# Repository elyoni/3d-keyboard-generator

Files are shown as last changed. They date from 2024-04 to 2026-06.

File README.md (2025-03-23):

# 3D Keyboard Builder

## Motivation (Short Version)

After experimenting with various custom keyboards, including the Ergodox and my own hand-built designs, I realized I wanted something more flexible and hot-swappable. My journey led me to a project that inspired me to create my own fully customizable keyboard, allowing me to test different layouts and components. This project not only solves my ergonomic needs but also provides the creative freedom to explore new features. <F12>

[Go here to read the full motivation story](<#motivation-(full-version)>)

## Project Description

This application takes a JSON file output from KLE and generates three STL files that are ready for 3D printing:

1. **Plate**: The top layer that holds the switches.
2. **PCB**: The layer designed to house the electronic components.
3. **Bottom**: The bottom layer, which encloses the keyboard.

The script processes each element of the KLE JSON to create a precise, functional 3D model for your custom keyboard.

## Supported Parts

### Keys

- **Cherry MX switches**

```json
[{sm:"cherry",a:7},"Q","W","E","R"],
["A",{w:2},"S","F"],
["Z","X","C"],
[{r:30,y:-3,x:4.25},"V"]
```

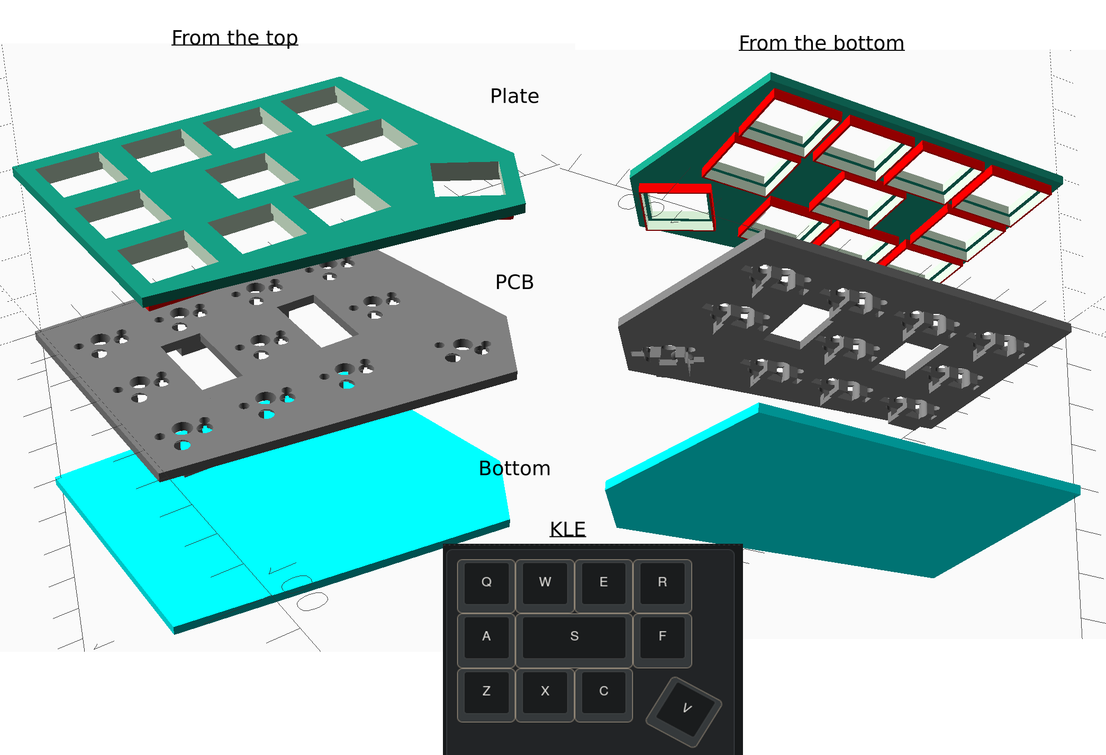
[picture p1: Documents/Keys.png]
Keys


### Arduino

- **Arduino** with Type C connection support

```json
[{ "y": 0.2, "x": 5.9, "sm": "arduino", "a": 5, "h": 2 }, "Arduino"]
```

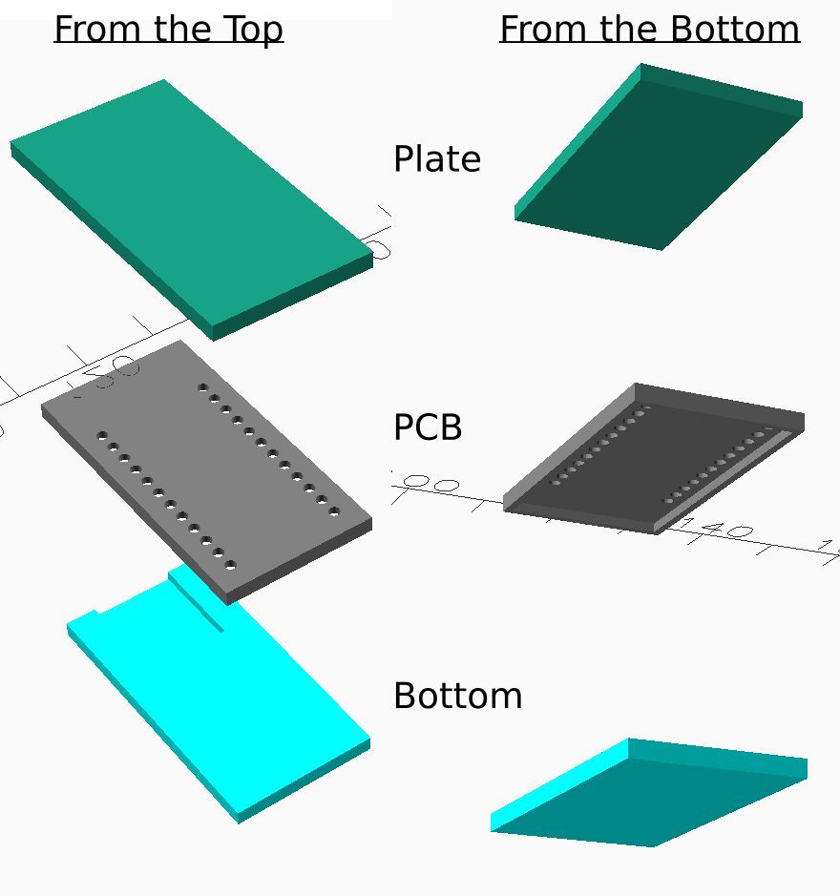
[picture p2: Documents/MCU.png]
Mcu


Links:

- [AliExpress: Arduino micro pro - ATMEGA32U4; $3.38](https://www.aliexpress.com/item/32840365436.html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)
- [AliExpress: Kailh Hot-swappable Cherry MX Switches 70pcs;$4.23](https://www.aliexpress.com/item/1005007052649640.html?spm=a2g0o.order_list.order_list_main.208.587a586aZr4UDJ)

### Pins (Layer Connectors)

- Pins act as placeholders for screws, providing modular assembly of keyboard layers.
- **Pin Types**:
  - **PinPcb**: Connects the Bottom layer to the PCB.
  - **PinPlate**: Connects the PCB to the Plate.
  - **PinB2P**: Direct connection between the Bottom layer and the Plate.

```json
[{sm:"pinpcb",w:0.5,h:0.5},"PinPcb"],
[{y:-0.25,sm:"pinplate",w:0.5,h:0.5},"PinPlate"],
[{y:-0.25,sm:"pinb2t",w:0.5,h:0.5},"PinB2P"]
```

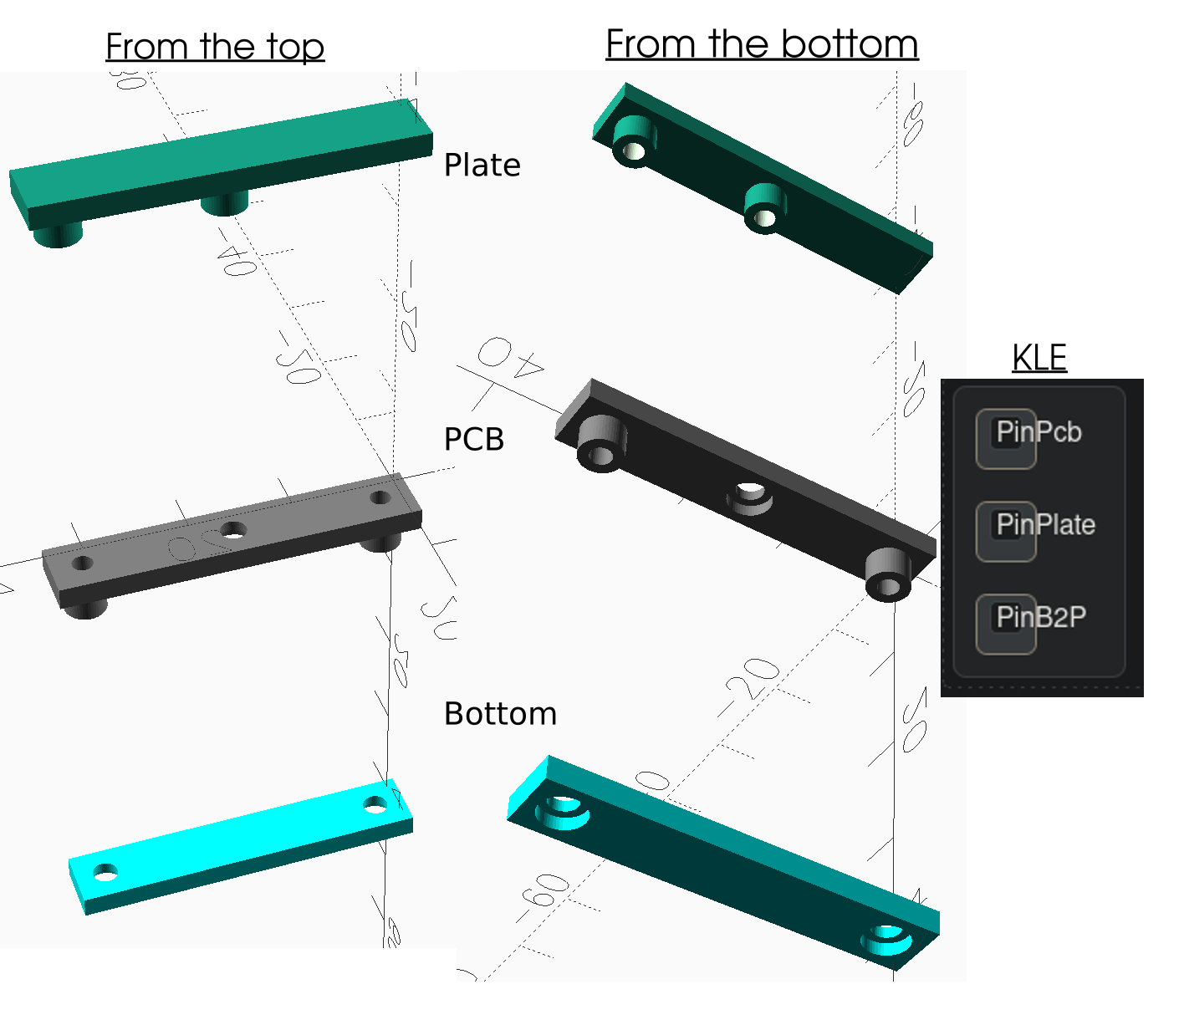
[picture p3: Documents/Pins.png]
Pin


### Split Keyboard Connector

- **TRRS Connector**: Support for split keyboard designs with TRRS connections.

Links:

- (AliExpress: TRRS 3.5 MM Audio Jack; $1.70)[https://www.aliexpress.com/item/33029465106.html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]
- (AliExpress: TRRS Coiled Spiral Cable 5~40cm; $1.69)[https://www.aliexpress.com/item/1005006141489472.html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]
- (AliExpress: TRRS Coiled Spiral Cable Up to 1.5m; $1.35) [https://www.aliexpress.com/item/33001682979.html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]

### Text

- Custom text can be engraved onto the plate.

## Real Keyboard Examples

### TEZ3 (Travel Easy Gen 3)

```json
[{x:1.9,sm:"pinplate",w:0.5,h:0.5},"PPlate",{x:-0.4,sm:"cherry"},"E",{x:2.3,sm:"arduino",a:5,h:2},"Arduino"],
[{y:-0.97,x:0.75,sm:"pinpcb",a:4,w:0.5,h:0.5},"PinPcb",{x:3.5,w:0.5,h:0.5},"PinPcb"],
[{y:-0.9,x:1,sm:"cherry"},"W",{x:1},"R",{x:-0.1,sm:"pinplate",w:0.5,h:0.5},"PPlate"],
[{y:-0.9,w:0.5,h:0.5},"PPlate"],
[{y:-0.98,x:4,sm:"cherry"},"T"],
[{y:-0.87},"Q"],
[{y:-0.38,x:2},"D"],
[{y:-0.87,x:1},"S",{x:1},"F"],
[{y:-0.98,x:1.9,sm:"pinplate",w:0.5,h:0.5},"PPlate",{x:0.5,sm:"pinpcb",w:0.5,h:0.5},"PinPcb"],
[{y:-0.9,x:4,sm:"cherry"},"G"],
[{y:-0.97,x:5,p:"TEZ3\\n  Y.E",sm:"platetext",a:7},""],
[{y:-0.9,sm:"cherry",a:4},"A"],
[{y:-0.95,x:3.9,sm:"pinplate",w:0.5,h:0.5},"PPlate"],
[{y:-0.43,x:2,sm:"cherry"},"C"],
[{y:-0.87,x:1},"X",{x:1},"V"],
[{y:-0.88,x:4},"B"],
[{y:-0.87},"Z"],
[{y:-0.5,x:1.9,sm:"pinplate",w:0.5,h:0.5},"PPlate"],
[{y:-0.73,x:3.9,w:0.5,h:0.5},"PPlate"],
[{y:-0.87,w:0.5,h:0.5},"PPlate",{x:0.5,sm:"pinpcb",w:0.5,h:0.5},"PinPcb"],
[{y:0.25,x:5.75,w:0.5,h:0.5},"PinPcb"],
[{y:-0.75,x:3.75,w:0.5,h:0.5},"PinPcb"],
[{r:30,rx:5,ry:3.25,y:1,x:-1,sm:"cherry",a:7},"","",""],
[{y:-0.8,x:-0.1,sm:"pinplate",a:4,w:0.5,h:0.5},"PPlate",{x:0.5,w:0.5,h:0.5},"PPlate"],
[{r:90,rx:5.25,ry:1.2,y:-1.1,x:1.85,sm:"trrs",a:5,w:0.5},"trrs"]
```

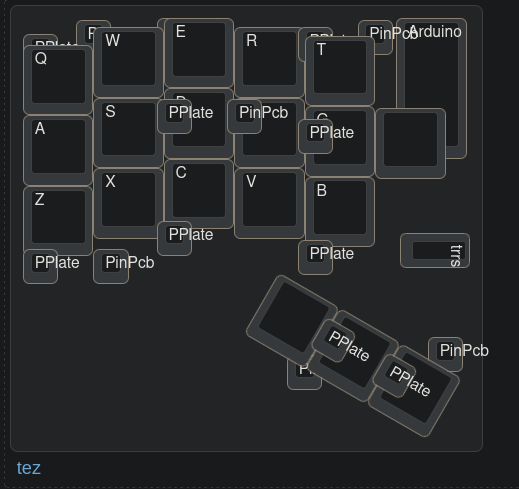
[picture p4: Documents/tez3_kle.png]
TEZ3 KLE Output


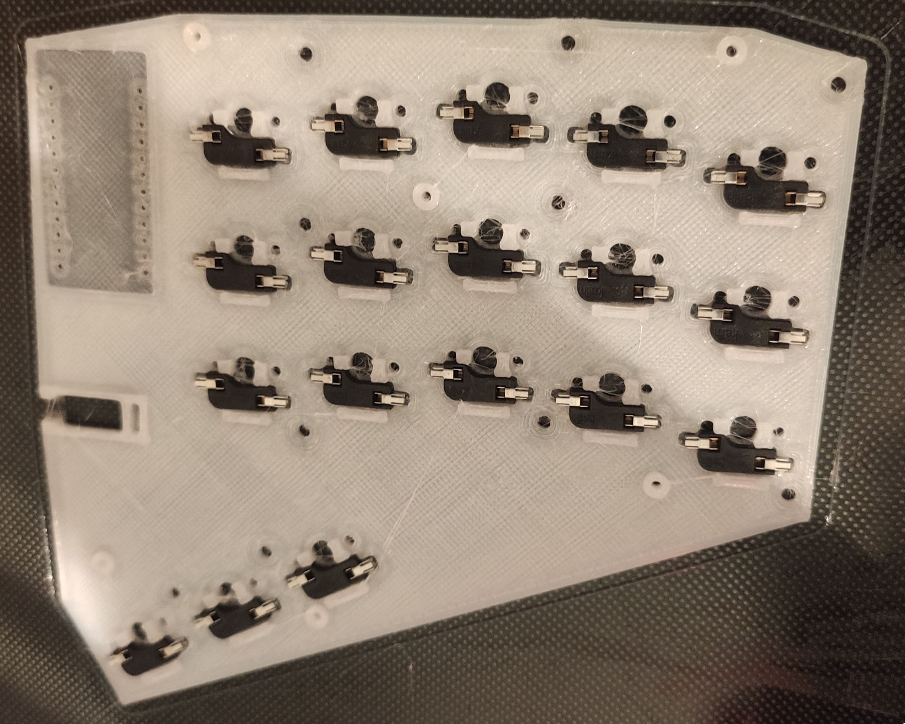
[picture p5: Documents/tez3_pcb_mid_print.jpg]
TEZ3 PCB Mid Print

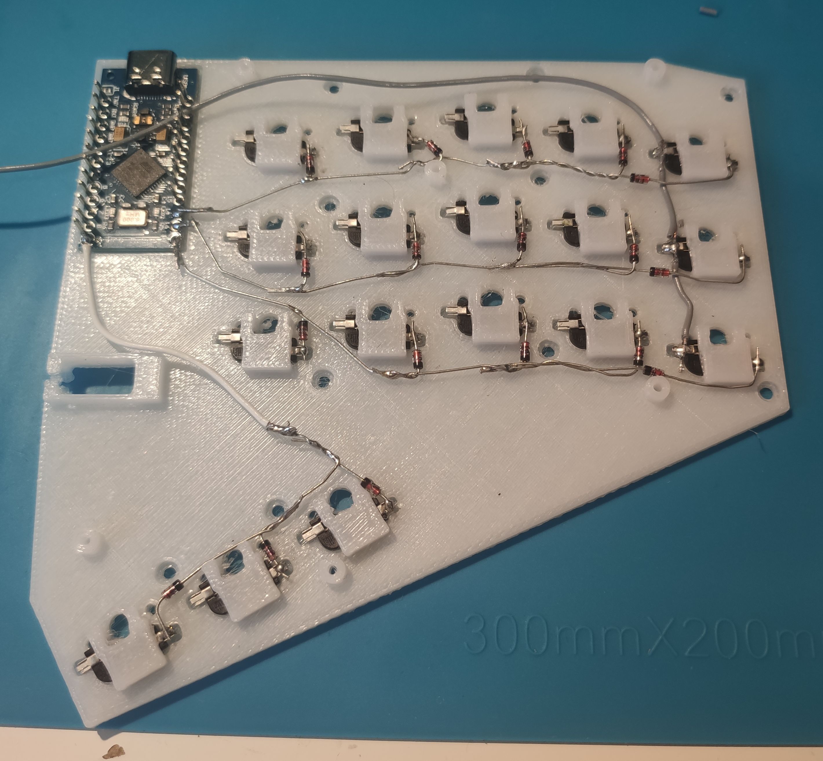
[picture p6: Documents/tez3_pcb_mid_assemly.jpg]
TEZ3 PCB Mid Assembly

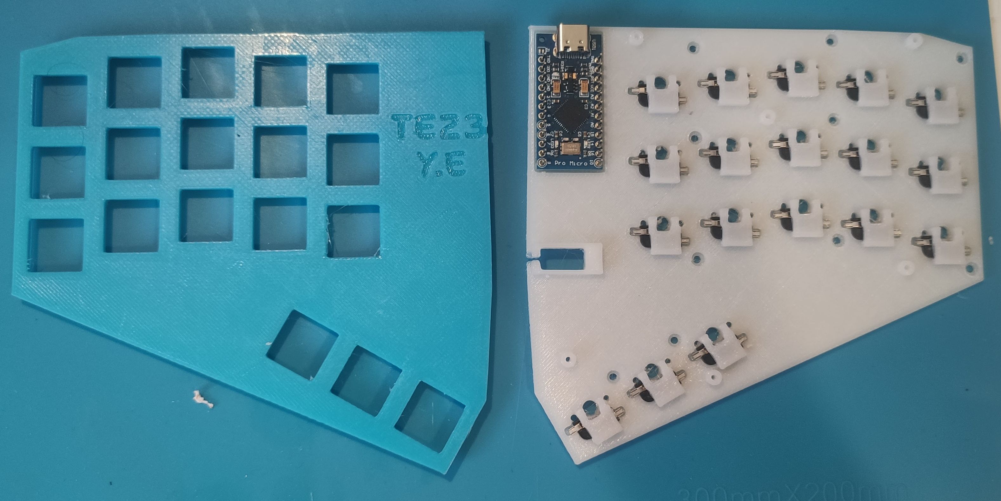
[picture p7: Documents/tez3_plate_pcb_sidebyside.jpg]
TEZ3 Plate And PCB Side By Side

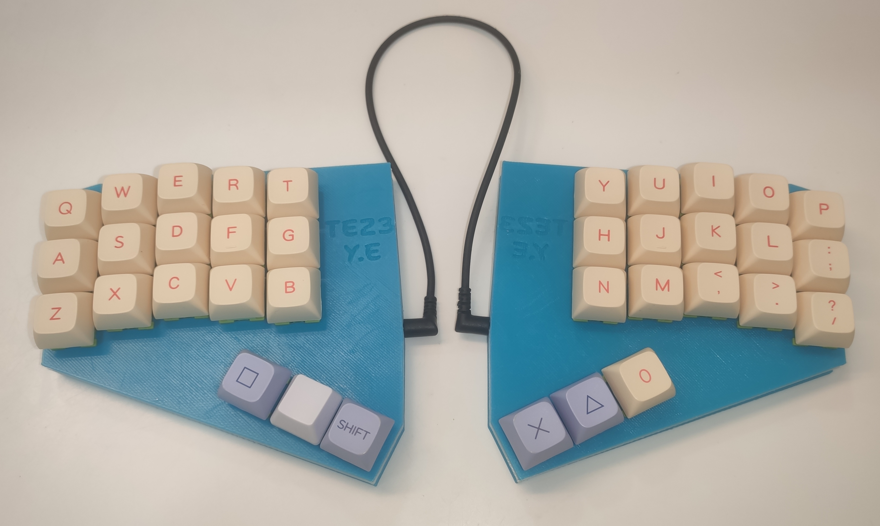
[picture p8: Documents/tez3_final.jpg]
TEZ3 Final Product


### How to add new part:

WIP

## Left Over:

- Support Kailh switch (Low Profile)
- JSON input

## Motivation (Full Version)

In 2020, my brother gave me his Ergodox keyboard [here’s a picture of the Ergodox](Documents/ergodox.jpg). At first, I struggled to find a comfortable configuration, constantly tweaking the settings every 10 minutes. I limited myself to using the Ergodox for 30 minutes daily since it reduced my work performance. After a few weeks, however, I became comfortable and switched to using the Ergodox full-time.

When my job announced that we needed to return to the office, I decided to build my own keyboard—one for home and one for the office. I wanted to keep it as affordable as possible, so I bought a bamboo cutting board from IKEA, a plate, keys, and keycaps from AliExpress. I carved out space in the cutting board for the plate and keys, which took over 4 hours. Then, I hand-wired all the keys and called the keyboard "TEZ" (Travel Easy). After using it for a few months, I realized I didn’t really like it and went back to carrying my Ergodox everywhere.

During this time, I learned a few things:

1. I prefer fewer keys and now use just 36.
2. To comfortably use the three thumb keys, I needed to shift them slightly to the right (on the left side of the keyboard).
3. I wanted the keys to be hot-swappable.

After a lot of research, I found a project called 3D-Printable Hotswap Keyboard PCB Generator. The creator, 50an6xy06r6n, came up with a clever way to achieve hot-swappability by using diodes and column wires. I printed and soldered the parts and started using it. At first, I really liked it, but after a few months, some keys would stop working unless I pressed them hard, which became frustrating. Eventually, I gave up on it and returned to the Ergodox at home and work.

At this point, I realized I had two options:

1. Learn how to create a PCB and design the keyboard I wanted.
2. Start a new project similar to 50an6xy06r6n’s, but instead of using diodes and wires to connect the columns, use a proper hot-swappable connector.

Long story short, I decided to create my own project. There were several reasons: I wasn’t sure which layout I wanted, and I didn’t want to waste money on unwanted PCBs. By creating my own project, I could easily try different components like an LCD or a joystick. I chose Python and pythonsolid2 for my project because I don’t really like OpenSCAD and enjoy the flexibility Python provides.

## License

This project is licensed under a **Non-Commercial Use License**.  
You may use, modify, and share this code **only for personal and non-commercial purposes**.  
**Commercial use, distribution, or resale is strictly prohibited.**

For more details, see the [LICENSE](LICENSE.txt) file.

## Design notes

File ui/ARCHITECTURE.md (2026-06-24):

# Keyboard Generator — Architecture & Component Reference

## Coordinate Systems

| System | X | Y | Z | Unit |
|---|---|---|---|---|
| KLE JSON | right → | down ↓ | — | Key Units (KU) |
| Python / OpenSCAD | right → | up ↑ | out of board ↑ | mm |
| Three.js viewer | right → | up ↑ | out of board ↑ | mm |

**KLE → mm conversion:** multiply KU by the switch spacing.
- Cherry MX: `1 KU = 19.05 mm`
- Kailh Choc: `1 KU = 19.05 mm` (same in this project)

**KLE Y → mm Y:** flip sign. KLE absY=0 is the top; mm Y=0 is the bottom-left reference.

---

## Layer Stack (bottom-up)

```
 Z = (LAYER_THICKNESS + GAP) * 2  ┌──────────────────────────────┐  PLATE (light gray)
                                   │  key holes (14.03×14.03 mm)  │  2.16 mm thick
                                   │  + pin boss posts             │
                                   └──────────────────────────────┘
 Z = (LAYER_THICKNESS + GAP) * 1  ┌──────────────────────────────┐  PCB (dark green)
                                   │  hotswap socket footprints   │  2.16 mm thick
                                   │  + Arduino + TRRS body       │
                                   │  pin screw holes              │
                                   └──────────────────────────────┘
 Z = 0                             ┌──────────────────────────────┐  BOTTOM (dark gray)
                                   │  Arduino USB cutout           │  2.16 mm thick
                                   │  TRRS barrel opening          │
                                   │  pin screw holes              │
                                   │  camera mount boss (below)    │
                                   │  tilt legs (below)            │
                                   └──────────────────────────────┘
```

`BASIC_LAYER_THICKNESS = 2.16 mm`  
`BORDER_RADIUS = 2 mm` (rounded corners on all three layers)

---

## Board Outline (Convex Hull)

All three layers share the same 2D outline, computed as the convex hull of all component corners, then rounded with `BORDER_RADIUS`.

**Python method:** `Keyboard._draw_base_plate()` collects all four corners of each part (using the part's **physical size**, after applying rotation and border expansion), feeds them to `scipy.spatial.ConvexHull`, then calls `round2d(r=2)`.

**Physical sizes used for hull** (NOT the KLE w/h values):

| Component | Physical size (mm) |
|---|---|
| cherry / kailhchoc | `w * 19.05` × `h * 19.05` (KLE-scaled) |
| arduino | `19 × 39` (fixed) |
| trrs | `8.2 × 14.6` (fixed — socket body + barrel) |
| pinplate / pinpcb / pinb2t | `4 × 4` (outer diameter) |
| hole (wire pass-through) | `w * 14.03` × `h * 14.03` (KLE-scaled, uses 14.03mm hole spacing) |
| platetext | `1 × 1` (tiny, rarely affects hull) |
| cameramount_selftap / heatset | `14 × 14` (BOSS_OUTER_DIAMETER) |
| tiltleg | `10 × 10` (LEG_DIAMETER) |

> **Important:** Parts whose KLE `w` or `h` differ from their physical footprint must use physical size for the hull, NOT `w * 19.05`.

---

## Component-by-Layer Matrix

### CherryMxKey / KailhChocKey

| Layer | What happens |
|---|---|
| **Plate** | Switch hole `14.03 × 14.03 mm` cut through. Ring of reinforcement added around hole. |
| **PCB** | Hotswap socket footprint `14.03 × 14.03 mm` subtracted. STL model of hotswap socket embedded (offset +0.56 mm for Cherry). |
| **Bottom** | Nothing. |

### Arduino

Physical size: `19 mm × 39 mm`  
Orientation: long axis along Y. Top edge points toward the split connector side.

| Layer | What happens |
|---|---|
| **Plate** | Nothing (footprint_plate = None). |
| **PCB** | Full footprint `19 × 39 mm` subtracted (slot for the board). Two rows of 12 pin holes (d=1.5 mm, spaced 2.54 mm, starting 2.5 mm from edge, 15 mm apart). |
| **Bottom** | Header opening: `12 × (13+10) mm` slot cut through, offset toward USB end. |

### TRRS Jack (PJ-320A)

Physical size: `8.2 × 14.6 mm` (body: 6.2 × 12.4 mm + 2.2 mm barrel space)  
Often placed at `r=90` so the barrel points outward from the board edge.

| Layer | What happens |
|---|---|
| **Plate** | Nothing. |
| **PCB** | Full footprint `8.2 × 14.6 mm` subtracted. Barrel hole (d=5.3 mm, h=2.2 mm) cut through one side. PCB part rendered as socket body box + cavity. |
| **Bottom** | Body opening `6.2 × 6.2 mm` cut through (so the jack can be inserted from below). |

### PinPlate (plate ↔ PCB spacer)

Physical size: `4 mm diameter` cylinder post; contributes 4×4 mm to hull.

| Layer | What happens |
|---|---|
| **Plate** | Boss post added on TOP surface (solid 4mm OD cylinder, height = PCB spacing, with 2mm ID hole). Fills the cell gap in the board. |
| **PCB** | 2mm hole cut through (receives the pin shaft). Screw chamfer recess on PCB surface. |
| **Bottom** | Nothing. |

### PinPcb (PCB ↔ bottom spacer)

| Layer | What happens |
|---|---|
| **Plate** | Nothing. |
| **PCB** | Boss post added on TOP surface. 2mm hole cut through for screw. |
| **Bottom** | Screw chamfer recess + 2mm through-hole. |

### PinFromBottomToPlate / pinb2t (bottom ↔ plate)

Combines PinPlate and PinPcb. Puts a boss on both PCB (for spacer) and plate, and screw recesses on both PCB and bottom.

### Hole (wire pass-through)

Physical size: `w * 14.03 × h * 14.03 mm`

| Layer | What happens |
|---|---|
| **Plate** | Nothing. |
| **PCB** | Slot cut through. |
| **Bottom** | Nothing. |

### PlateText (engraved text)

Physical size: `1 × 1 mm` (does not significantly affect hull).

| Layer | What happens |
|---|---|
| **Plate** | Text engraved (subtracted) from plate surface using `text3d`. |
| **PCB** | Nothing. |
| **Bottom** | Nothing. |

### CameraMount (self-tap or heat-set)

Physical size: `14 mm diameter` boss; contributes 14×14 mm to hull.

Protrudes **downward** from the bottom layer outer face (toward the desk).

| Layer | What happens |
|---|---|
| **Plate** | Nothing. |
| **PCB** | Nothing. |
| **Bottom** | Boss added below: 4 mm conical chamfer flare at board surface + main cylinder (d=14 mm, h=6-10 mm) + blind screw hole (d=5.5 mm for self-tap, d=7 mm for heat-set). |

### TiltLeg

Physical size: `10 mm diameter` cylinder; contributes 10×10 mm to hull.  
Height is **auto-calculated** by the Python code from the tilt plane defined by:
`leg_height = boss_height × |leg_x − outer_edge_x| / |boss_x − outer_edge_x|`

| Layer | What happens |
|---|---|
| **Plate** | Nothing. |
| **PCB** | Nothing. |
| **Bottom** | Leg added below: 4 mm conical chamfer + straight shaft + hemisphere tip (d=10 mm). |

---

## Part Placement: Rotation

All parts support optional rotation from KLE `r`, `rx`, `ry`:

```
absX, absY  → top-left of part cell in KU (KLE coordinates)
rx, ry      → rotation pivot in KU
r           → rotation angle in degrees (KLE: clockwise when Y-down)
```

**Python:** the center point is first computed as `(absX, absY) + physicalSize/2` (in mm), then rotated around `(rx, ry) * spacing` using a standard 2D rotation matrix.

**Critical:** the center that gets rendered is the **post-rotation** center. The convex hull is also computed using the **post-rotation corners** of each part.

---

## Python Rotation Pipeline (Exact Math)

### Coordinate convention

Python receives KLE values directly — **no Y-axis flip**. So Python's Y increases downward (same as KLE), even though OpenSCAD normally uses Y-up. The resulting SCAD geometry is "upside-down" relative to OpenSCAD convention, but since all parts share the same convention the relative positions are correct.

### Step-by-step for every part

**Input** (from pykle_serial / JS parser):
| Field | Meaning |
|---|---|
| `absX / part.x` | Top-left corner X of the key cell, in KU |
| `absY / part.y` | Top-left corner Y of the key cell, in KU (Y-down) |
| `r / rotation_angle` | Rotation angle in degrees |
| `rx / rotation_x` | Rotation pivot X, in KU |
| `ry / rotation_y` | Rotation pivot Y, in KU |
| `w, h / width, height` | Key cell size in KU |

**Step 1 — Convert to mm**
```
pos_mm    = (absX * spacing,  absY * spacing)       # top-left in mm
pivot_mm  = (rx * spacing,    ry * spacing)          # pivot in mm
```

**Step 2 — Determine physical size**

If the class has a `spacing` attribute (CherryMxKey, KailhChocKey), size depends on the KLE cell:
```
size_mm = (w * class.spacing.x,  h * class.spacing.y)
```
If the class has a **fixed** size (Arduino, TRRS, pins, camera mount, tilt leg):
```
size_mm = class.size   # e.g. XY(19, 39) for Arduino — KLE w/h are IGNORED
```

**Step 3 — Compute unrotated center**
```
center_pre = (pos_mm.x + size_mm.w / 2,  pos_mm.y + size_mm.h / 2)
```

**Step 4 — Rotate center around pivot**

Python uses the standard 2D rotation matrix:
```
R = [[cos(r°), -sin(r°)],
     [sin(r°),  cos(r°)]]

center_post = R @ (center_pre - pivot_mm) + pivot_mm
```

Because Python's Y is down (KLE convention) and this matrix is the "CCW in Y-up" matrix, it acts **clockwise** visually — which matches KLE's `r` field semantics.

**Step 5 — Draw at local origin, then rotate and translate**
```python
# In every draw_*_part / draw_*_footprint method:
result = self._draw_*()         # build shape centered at (0, 0, 0)
result = result.rotate(self.angle_rotation)           # rotate in place (Z-axis, CW in Y-down)
result = result.translate(center_post.x, center_post.y, 0)  # move to final position
```

**Key invariant**: `center_post` (called `center_point` in Python) is the only position stored. Every draw call uses `.rotate(angle).translate(center_point.x, center_point.y)`.

---

## Per-Component Geometry at Local Origin

Each component's `_draw_*` methods build geometry **centered at (0, 0)** before rotation/translation.

### CherryMxKey / KailhChocKey

| Method | Geometry at origin |
|---|---|
| `_draw_plate_footprint` | 14.03 × 14.03 × 5 mm cube (hole cut-out) + 14.03+3 reinforcement ring |
| `_draw_pcb_footprint` | 19.05 × 19.05 × 5 mm cube (full cell footprint cut-out) |
| `_draw_pcb_part` | STL hotswap socket model, offset +0.56 mm in Z for Cherry |

### Arduino

Fixed size 19 × 39 mm. Long axis = Y. USB end is at the −Y side (smaller Y in KLE space).

| Method | Geometry at origin |
|---|---|
| `_draw_pcb_footprint` | 19 × 39 × 5 mm cube |
| `_draw_pcb_part` | 12 pin holes × 2 rows (d=1.5 mm, spacing 2.54 mm, rows 15 mm apart) |
| `_draw_bottom_part_addition_sub` | 12 × (13+10) mm slot near the −Y (USB) end |

### TRRSJack (PJ-320A)

Fixed size 8.2 × 14.6 mm. Default rotation r=90 (barrel points in X direction).

| Method | Geometry at origin |
|---|---|
| `_draw_pcb_footprint` | 8.2 × 14.6 × 5 mm cube |
| `_draw_pcb_part` | socket body box (6.2 × 12.4 × 5.2) + barrel cylinder (d=5.3, h=2.2) on Y− side |
| `_draw_bottom_part_addition_sub` | ≈6.2 × 6.2 mm slot centered at origin |

### Pin (PinPlate / PinPcb / PinFromBottomToPlate)

Fixed size 4 × 4 mm. All three are cylinders centered at (0,0).

| Param | Value |
|---|---|
| Outer diameter | 4 mm (r=2 mm) |
| Inner hole diameter | 2 mm (r=1 mm) |
| Boss height | varies (≈ PCB layer gap) |

### CameraMount (self-tap / heat-set)

Fixed size 14 × 14 mm. Protrudes **downward** (−Z) from the bottom layer.

| Param | Value |
|---|---|
| BOSS_OUTER_DIAMETER | 14 mm |
| boss_height | 10 mm (self-tap), 6 mm (heat-set) |
| Screw hole d | 5.5 mm (self-tap), 7 mm (heat-set) |
| Conical chamfer | 4 mm at the board surface |

### TiltLeg

Fixed size 10 × 10 mm. Protrudes **downward** (−Z). Height auto-calculated from tilt plane:
```
leg_height = boss_height × |leg_x − outer_edge_x| / |boss_x − outer_edge_x|
```

| Param | Value |
|---|---|
| LEG_DIAMETER | 10 mm |
| Tip shape | hemisphere |
| Conical chamfer | 4 mm at board surface |

---

## How the JS 3D Viewer Maps This

### Center position

```js
function getCompCenterMm(comp) {
  const { w, h } = getPhysSize(comp);  // physical mm, NOT comp.w * SPACING
  let cx = comp.absX * SPACING + w / 2;
  let cy = comp.absY * SPACING + h / 2;
  if (comp.r !== 0) {
    const rad = comp.r * Math.PI / 180;
    const px = comp.rx * SPACING, py = comp.ry * SPACING;
    // Same R matrix as Python — CW in Y-down
    const r = rotatePoint(cx, cy, px, py, rad);
    cx = r.x; cy = r.y;
  }
  return { mmX: cx, mmY: cy };  // KLE mm coords (Y-down)
}
```

This is mathematically identical to Python's `center_point` computation.

### Three.js mesh placement

```js
const { mmX, mmY } = getCompCenterMm(comp);
const sx = mmX - shapeCx;           // center X in shape space
const sy = -(mmY - shapeCy);        // Y-flip: KLE Y-down → Three.js Y-up
mesh.position.set(sx, sy, z);
mesh.rotation.z = -comp.r * Math.PI / 180;  // negate because Y-flip reverses CW/CCW
```

Why negate the rotation: flipping Y transforms a CW rotation (in KLE Y-down) into a CCW rotation (in Three.js Y-up). Negating `rotation.z` compensates, making the mesh appear correctly oriented.

### Switch holes / rectangular cutouts

Rectangular holes in the board layers (key switch holes, TRRS slot, Arduino opening) are drawn in local space around `(0, 0)`, then rotated by `comp.r` **around their own center**, then translated to `(mmX, mmY)`:

```js
// CORRECT: rotate corners around own center, then translate
function addRectHole(shape, cx_mm, cy_mm, hw, hh, rotRad, shapeCx, shapeCy) {
  const cos = rotRad ? Math.cos(rotRad) : 1;
  const sin = rotRad ? Math.sin(rotRad) : 0;
  const raw = [[-hw,-hh],[-hw,hh],[hw,hh],[hw,-hh]];
  const pts = raw.map(([x, y]) => ({
    x: cx_mm + x*cos - y*sin,
    y: cy_mm + x*sin + y*cos,
  }));
  // ...add as THREE.Path hole to shape
}
```

**Common mistake**: passing `(comp.rx * SPACING, comp.ry * SPACING)` as pivot to `rotatePoint` after already using `getCompCenterMm` produces a **double rotation** — the pre-rotated center gets rotated a second time around the KLE pivot, placing the hole at a completely wrong position.

---

## Differences Between Website Output and OpenSCAD

The following bugs exist in the Three.js viewer (`ui/js/viewer3d.js`):

| Bug | Effect | Root cause |
|---|---|---|
| Rotated parts placed at unrotated center | TRRS, thumb keys appear at wrong position in 3D | Viewer uses `(absX + w/2) * 19.05` without rotating around pivot |
| Non-key parts use KLE w/h for size | Arduino, TRRS, pins, camera mount, tilt leg render at wrong size | Should use fixed physical sizes (see table above) |
| Pin cylinder radius 3.5–4 mm | Pins appear 2× too large | Should be OD=2 mm radius (d=4 mm), ID=1 mm radius (d=2 mm) |
| Convex hull uses KLE cell size | Board outline may be slightly off | Hull corners should use physical part size, not `w * 19.05` |
| Camera mount / tilt leg extrude upward into board | Geometry bleeds through the bottom layer | Should extrude downward from `z = LAYER_THICKNESS` |

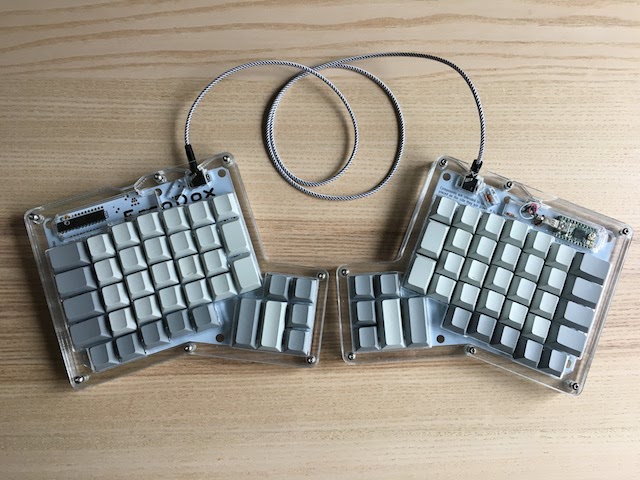
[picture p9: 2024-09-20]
Documents/ergodox.jpg

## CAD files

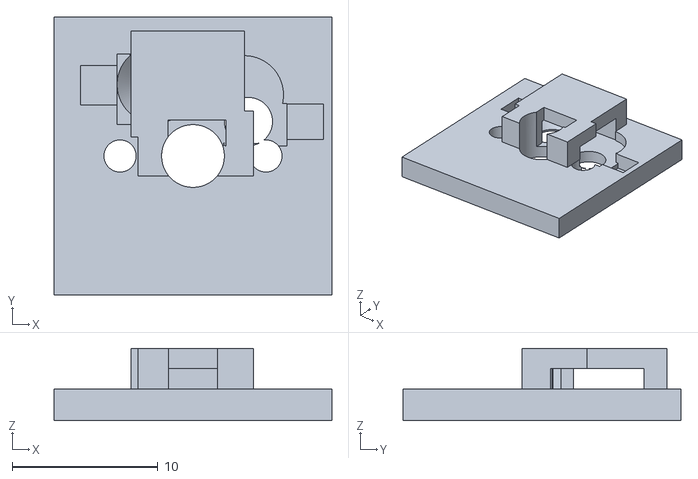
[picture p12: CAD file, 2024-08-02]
stl/KeyHotswap.stl
19.0 x 19.0 x 4.96

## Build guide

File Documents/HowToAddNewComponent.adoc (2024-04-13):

= How To Add New componentbase.p

Every component contains three shared variables:

. spacing: XY (Optional) Used for key components to support key's in default sizes
. size: XY The size of the component in mmXmm. If spacing is set will be overwritten by spacing * [hight, width]
. footprint_pcb: XY
. footprint_plate: XY

. draw_pcb_footprint(self) -> OpenSCADObject
. draw_plate_part(self) -> OpenSCADObject
. draw_plate_footprint(self) -> OpenSCADObject
. draw_plate_part_addition_add(self) -> OpenSCADObject
. get_openscad_obj(self) -> OpenSCADObject

= Plate

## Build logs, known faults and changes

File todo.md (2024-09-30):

# TO DO List
- [.] Features to add
    - [X] The option to generate the opposite side of the PCB (mirror objects)
    - [ ] Generate STL files, not only OpenScad files
    - [ ] Support JSON input files, not only hardcoded JSON
- [ ] Write a README
    - [ ] Explain how to build a keyboard
    - [ ] How to add new components
    - [ ] How to work with keyboard-layout-editor
    - [ ] How work with the split keyboard
    - [ ] Add links to Aliexpress. From where I bought this
- [o] Parts to Add
    - [x] Pin holder from the bottom through the PCB to the plate
    - [ ] Add more MCU components
        - [ ] Arduino pro micro (With micro USB)
        - [ ] NICE!NANO
    - [X] In the TRRS jack, add a hole in the bottom layer for the soldering
    - [X] Hole object, on the PCB layer. To allow passing wires. (Used for the leds)
    - [ ] Silicons pads - [Example|https://www.aliexpress.com/item/32514500567.html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,scm-url:1007.40050.354490.0,pvid:3f57431e-5068-4885-bbfb-9f682a15af95,tpp_buckets:668%232846%238114%231999&pdp_npi=4%40dis%21ILS%217.25%216.76%21%21%211.91%211.78%21%4021010c9c17245547970128946e85ea%2167366923642%21rec%21IL%21127936346%21XZ&utparam-url=scene%3ApcDetailBottomMoreOtherSeller%7Cquery_from%3A]

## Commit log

2024-04-13 [Fix] Verify the STL of the key is exist
2024-05-13 [WIP] Working on TRRS connector
2024-08-07 [Update] Improved the arduino header + cleanup the main script
2024-09-20 [Pins] Pin from the button to the plate
2024-09-30 [Hole] add hole object
2024-11-29 Add slight border radius to the case
2026-06-18 [Tests] Add tests, fix XY.__eq__, fix Arduino pattern
    - Add pytest + pytest-cov (58% coverage across 55 tests)
    - Add XY.__eq__ and __hash__ so footprint_pcb == XY(0,0) works correctly
    - Remove dead "easy case" string literal in XY.rotate
    - Arduino._draw_bottom_part_addition_sub: follow the template method
    pattern (override private method, let base class apply translate)
    - Move `import operator` to module level in arduino.py
2026-06-19 [Refactor] Replace get_part_obj if-elif chain with dict registry
    Adding a new part now only requires adding the class to _PART_REGISTRY.
2026-06-19 [Refactor] Consistent template method pattern across all draw_* methods
    - Add _draw_pcb_footprint() so subclasses can customize it the same way
    _draw_plate_footprint() already works (PinPlate._draw_pcb_footprint was
    previously dead code, now it runs)
    - Key: move pcb footprint geometry into _draw_pcb_footprint (private),
    letting the base class handle rotate/translate
    - Eliminate double _draw_*() calls in every draw_* wrapper — cache result
    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
2026-06-19 [Fix] Remaining code quality issues
    - keys.py: remove debug() artifact from _draw_plate_part_addition_sub
    - keys.py: fix KailhChocKey.openscad_file_path (wrong path, never loaded)
    - keyboard.py: draw_pcb now uses union() like draw_plate (was using [])
    - plate_text.py: fix potential UnboundLocalError and remove no-op ternary
    - main.py: remove redundant bottom = draw_bottom() line in split path
2026-06-20 [Feature] Camera arm mount boss and auto-calculated tilt legs
    - CameraMountSelfTap: 14mm boss with 5.5mm pilot hole (1/4"-20 self-tap)
    - CameraMountHeatSet: 14mm boss with 7.0mm hole for brass heat-set insert
    - TiltLeg: leg whose height is auto-calculated so its tip lies exactly on
    the tilt plane defined by the boss and the keyboard's outer (right) edge
    - Keyboard._validate_and_set_leg_heights(): raises ValueError if the leg
    is not to the inner side of the boss, or if the boss is outside the
    keyboard body — otherwise computes required leg height geometrically
    - 17 new tests covering height math, error cases, and part registration
2026-06-21 [Test] Add camera_mount_test() layout and set it as main default
    - camera_mount_test(): 5+5 Cherry MX keys, two TiltLegs on inner side,
    one CameraMountSelfTap boss centred below the key cluster
    - Legs auto-calculated to 19.9mm (~10° tent angle)
    - main.py now generates this layout for visual verification
2026-06-21 Add CameraMount + TiltLeg support with tez_v3 layout
    - camera_mount.py: fix boss hole (pre-cut hole inside boss via CSG so
    _draw_bottom_part_addition_sub only cuts through the base plate);
    add hemispherical tip to TiltLeg for a rounded foot
    - keyboard.py: add _get_left_edge_x(); update _validate_and_set_leg_heights()
    to support both orientations — legs left of boss (right-half keyboard,
    outer edge on right) and legs right of boss (left-half keyboard, outer
    edge on left); formula auto-detected from leg position
    - hardcoded_jsons.py: add tez_v3_with_mount() with CameraMountSelfTap at
    x≈57mm and two TiltLegs at x≈109mm (auto-calculated height ≈19.1mm)
    - main.py: switch to te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
2026-06-21 Fix boss and leg orientation + make boss hole blind
    - Boss and legs now protrude from the desk-facing (outer) face of the
    bottom plate (z > BASIC_LAYER_THICKNESS) instead of from the PCB-facing
    face (z < 0). This is the correct print orientation — no flip needed in
    the slicer, and the features point toward the desk when assembled.
    - Boss screw hole is now a blind hole (stops at the plate surface, does
    not pass through the plate). Removed _draw_bottom_part_addition_sub
    from CameraMount since no through-hole is needed.
2026-06-21 Add conical chamfer at the base of boss and tilt legs
    A 2mm-wide conical flare where each feature meets the plate surface:
    - improves layer adhesion at the critical junction
    - reduces stress concentration under load
    - gives the slicer a wider first few layers for each pillar
    Boss and legs still span their full declared heights; the chamfer is taken
    from the base section so the tip position (and tilt calculation) is unchanged.
2026-06-21 Increase chamfer size to 4mm for a stronger base flare
    CHAMFER_SIZE was 2mm — visible but not structurally convincing.
    4mm gives a noticeably wider flare at the plate/boss and plate/leg
    junctions, improving adhesion and reducing stress concentration.
2026-06-24 Add static web UI for visual keyboard layout editor
    Includes a canvas-based drag-and-drop editor, properties panel, KLE
    JSON serializer/parser, preset layouts, and a Three.js 3D viewer with
    per-layer visibility, exploded view, and correct hull winding so the
    bottom layer renders solid from all angles.
2026-06-26 Add JSON file loader and 3D generation from the web UI
    - keyboardgenerator/server.py: combined static + API server (port 8765).
    POST /api/generate accepts KLE JSON + settings, runs the Python keyboard
    generator, and returns a ZIP with plate.scad / pcb.scad / bottom.scad.
    - tusk ui now starts the combined server instead of a plain http.server,
    so both static serving and the API work from one process.
    - UI: "Load JSON file" button opens a file picker and loads any KLE JSON
    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
2026-06-27 Fix: don't emit r on non-first keys in a rotated KLE row
    addCompProps was adding r:<angle> to every key in a rotated row.
    pykle_serial rejects rotation on any key except the first in a row,
    causing 'rotation can only be specified on the first key in a row'
    when the Generate 3D button was clicked with layouts that use
    rotation (e.g. TEZ v3 thumb cluster at r:30).
    Fix: pass skipR=true for all non-first keys in a rotated row.
    Claude-Session: https://claude.ai/code/session_015gxDAzXt3ej58muyGUsJX8
